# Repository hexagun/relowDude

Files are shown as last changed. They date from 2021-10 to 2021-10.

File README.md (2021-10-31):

# relowDude
Controller for reflow oven
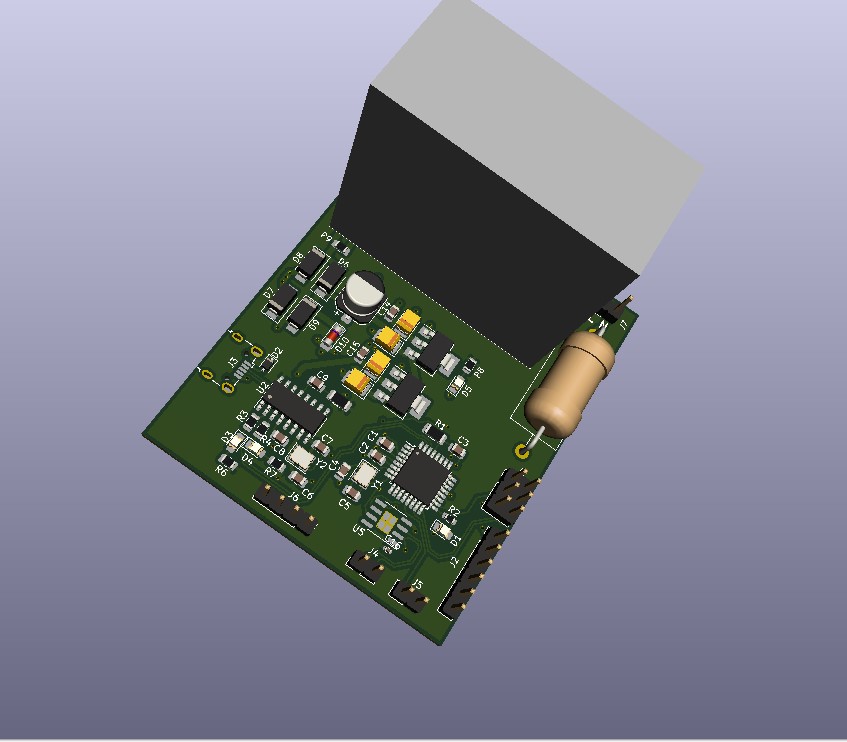
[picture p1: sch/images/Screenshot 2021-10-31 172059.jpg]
top1

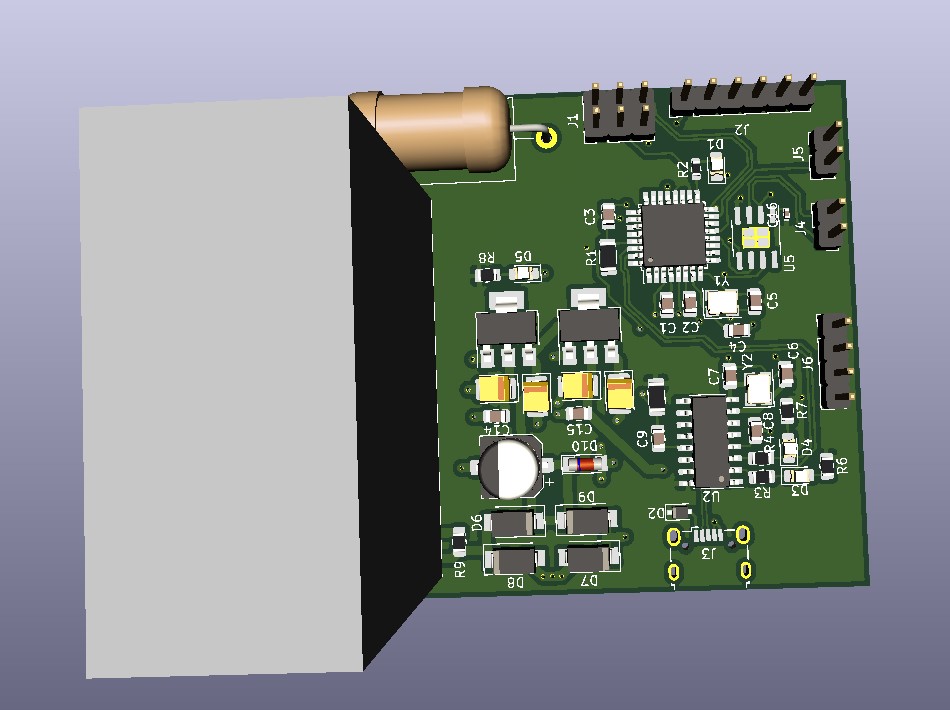
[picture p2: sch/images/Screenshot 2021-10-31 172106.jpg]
top2

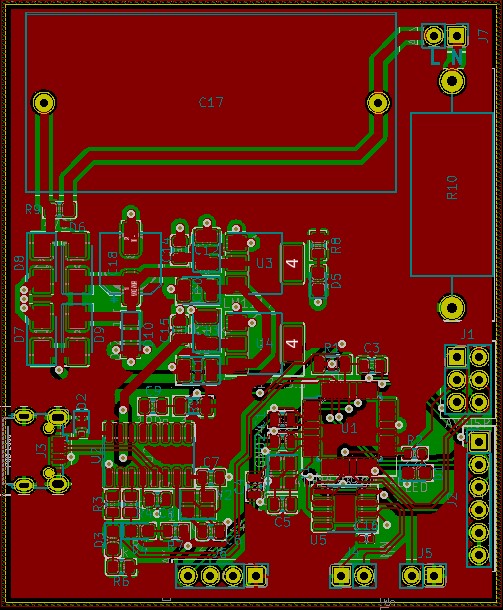
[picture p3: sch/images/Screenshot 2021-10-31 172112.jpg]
top3


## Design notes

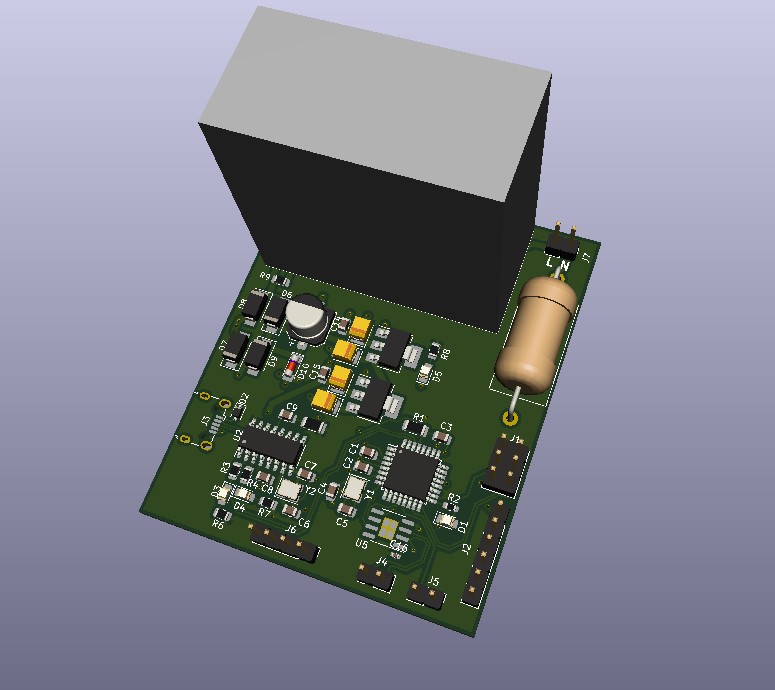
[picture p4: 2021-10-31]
sch/layoutFront.jpg

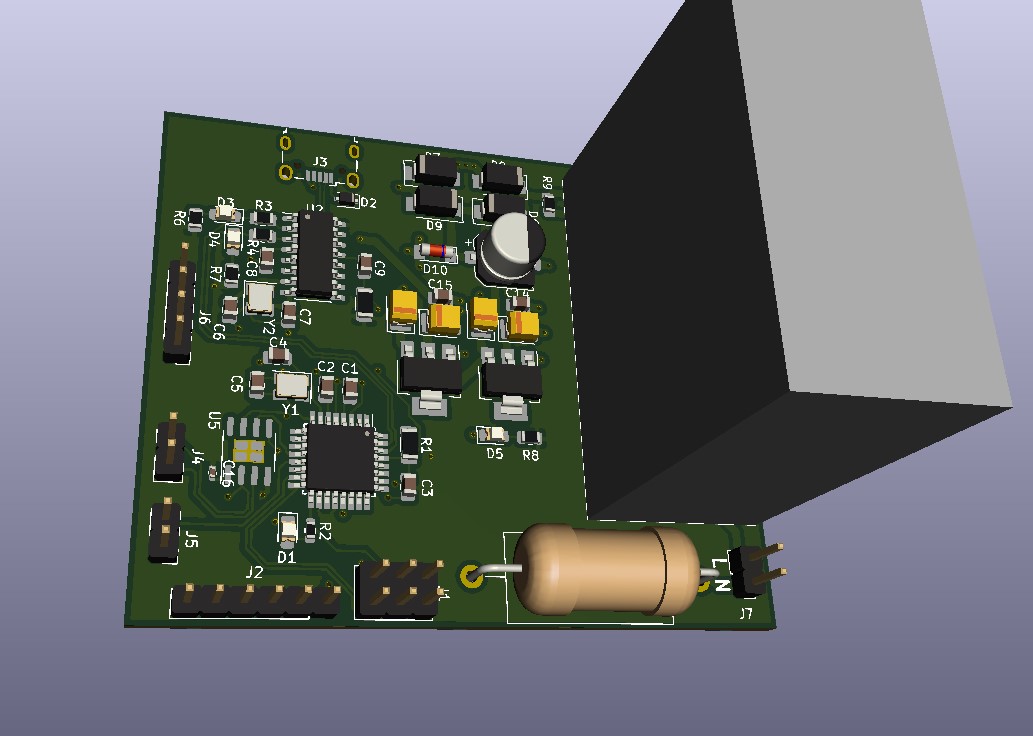
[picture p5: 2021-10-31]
sch/layoutFront1.jpg

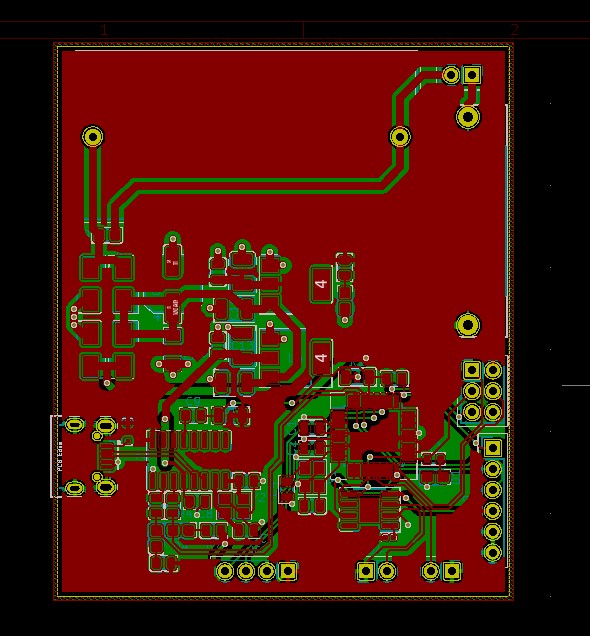
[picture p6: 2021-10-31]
sch/layout.jpg

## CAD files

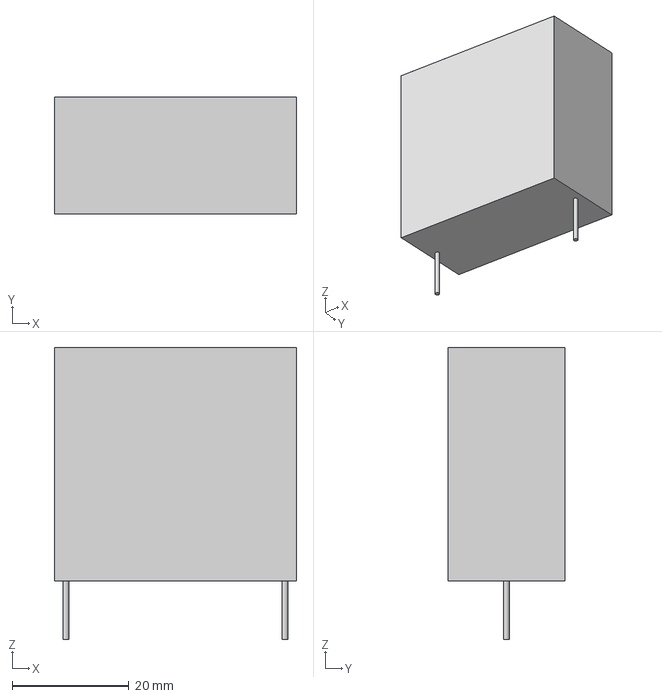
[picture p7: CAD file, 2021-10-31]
sch/R475W42205001K v1.step
41.5 x 20.0 x 50.0 mm

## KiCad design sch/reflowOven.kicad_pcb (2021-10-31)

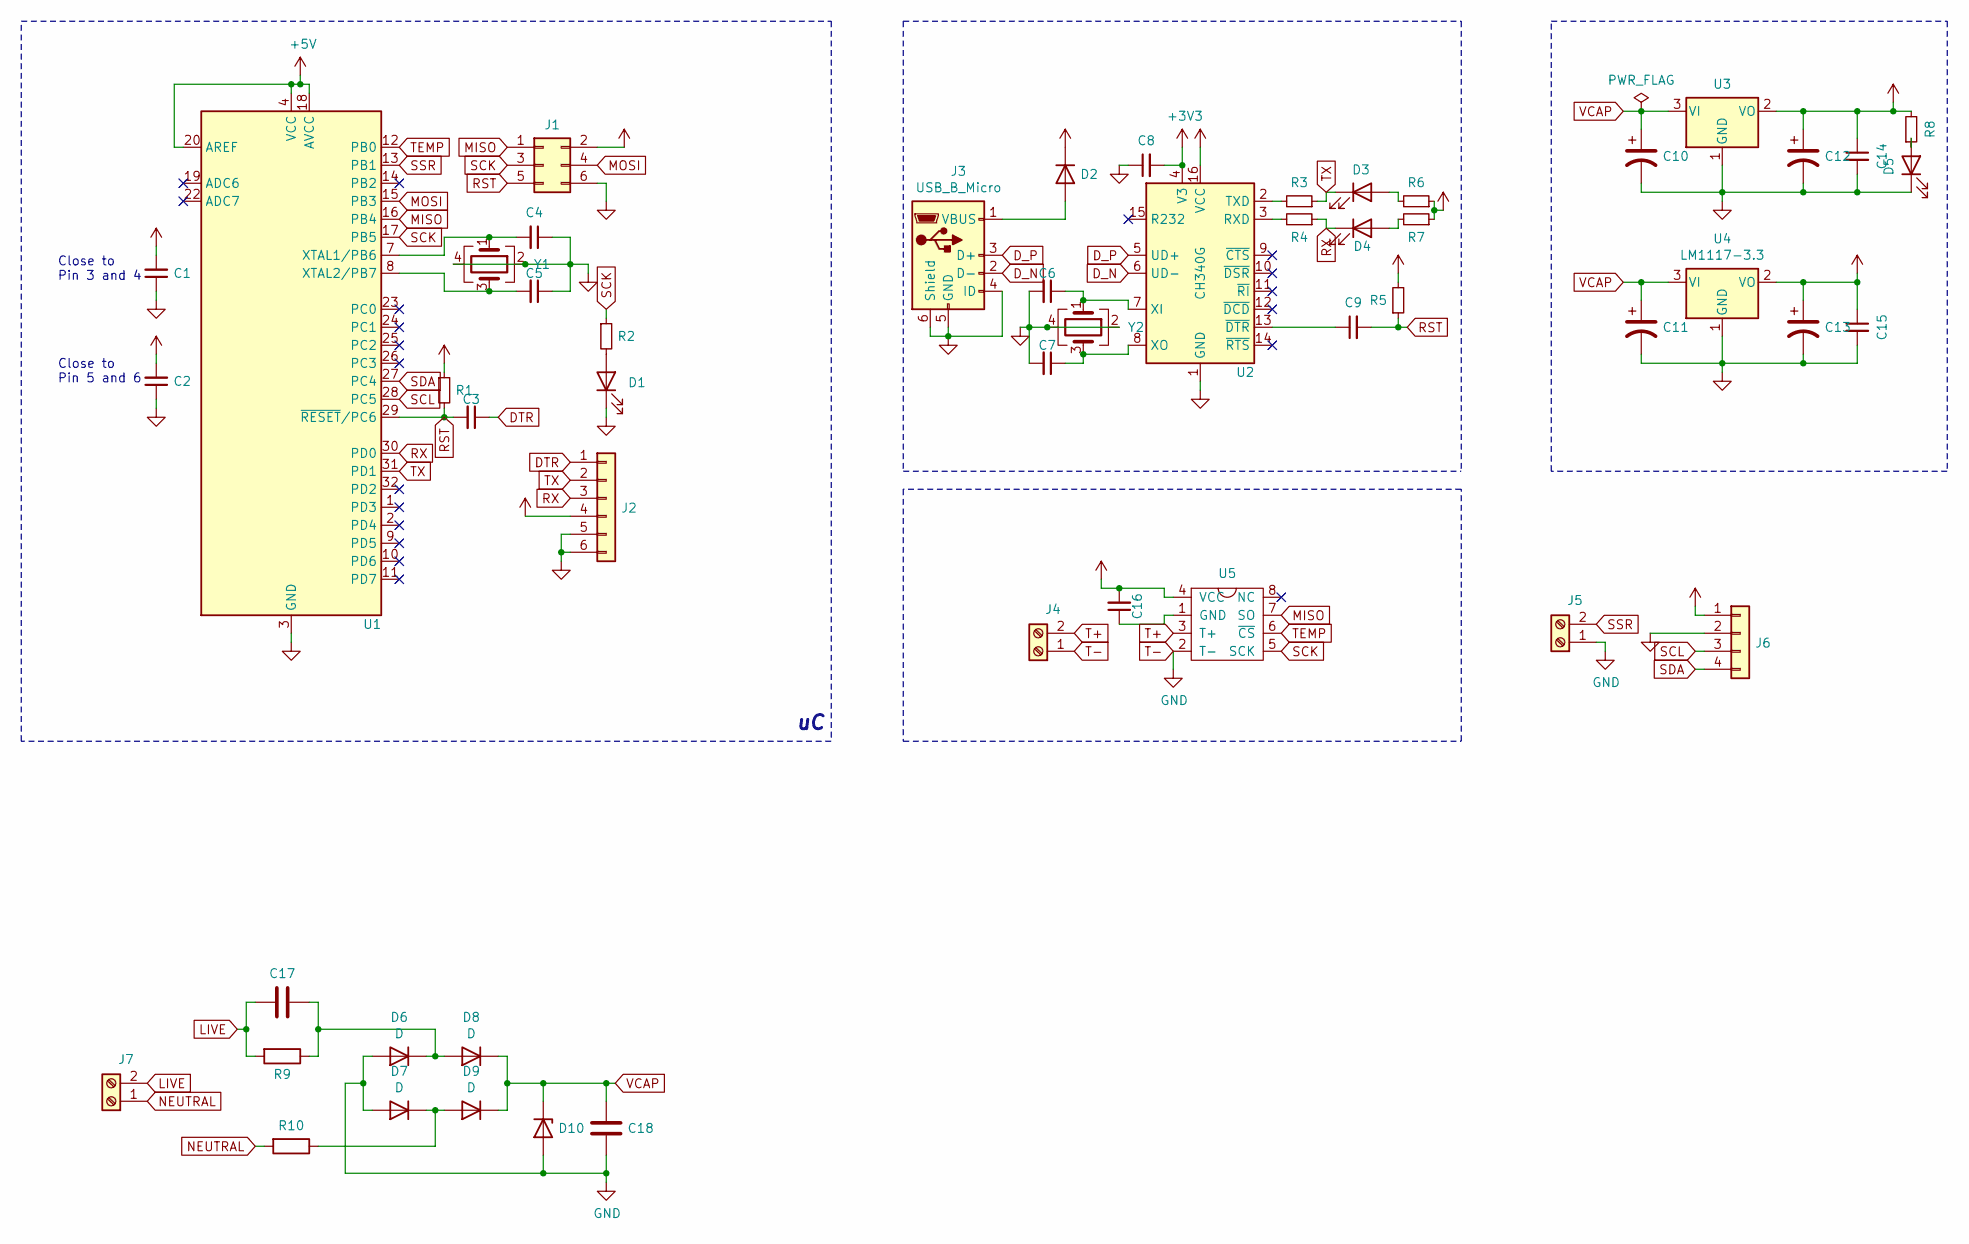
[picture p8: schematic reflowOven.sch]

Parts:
C1, C2, C3, C8, C9, C14, C15: 100n; C_0805_2012Metric; JLCPCB C49678
C4, C5, C6, C7: 22p; C_0805_2012Metric; JLCPCB C1804
C10, C11, C12, C13: 10u; CP_EIA-3528-21_Kemet-B; JLCPCB C119050
C16: 0.1u; C_0402_1005Metric; JLCPCB C361198
C17: 2.2u; R475W42205001K; Mouser R475W42205001K
C18: 47u; CP_Elec_6.3x5.9; JLCPCB C311666
D1: LED; LED_0805_2012Metric_Castellated; JLCPCB C84256
D2: 1N4007; D_SOD-323F; JLCPCB C193404
D3: TX; LED_0805_2012Metric_Castellated; JLCPCB C84256
D4: RX; LED_0805_2012Metric_Castellated; JLCPCB C84256
D5: ON; LED_0805_2012Metric_Castellated; JLCPCB C84256
D6, D7, D8, D9: D; D_SMA; JLCPCB C727081
D10: D_Zener; D_MiniMELF; JLCPCB C8061
J1: AVRISP; PinHeader_2x03_P2.54mm_Vertical
J2: UART; PinHeader_1x06_P2.54mm_Vertical
J3: USB_B_Micro; USB_Micro-B_Wuerth_629105150521; JLCPCB C879723
J4: TEMPCONN; PinHeader_1x02_P2.54mm_Vertical
J5: SSRCONN; PinHeader_1x02_P2.54mm_Vertical
J6: DISPLAY; PinHeader_1x04_P2.54mm_Vertical
J7: MAINS; PinHeader_1x02_P2.54mm_Vertical
R1, R5: 10k; R_1206_3216Metric; JLCPCB C17902
R2: 330; R_0603_1608Metric; JLCPCB C23140
R3, R4, R6, R7, R8: 1k; R_0805_2012Metric; JLCPCB C17513
R9: 470k; R_0805_2012Metric_Pad1.20x1.40mm_HandSolder; JLCPCB C17675
R10: 100; R_Axial_DIN0918_L18.0mm_D9.0mm_P25.40mm_Horizontal; Mouser 594-AC05W100R0J
U1: ATmega328P-AU; TQFP-32_7x7mm_P0.8mm; JLCPCB C14877
U2: CH340G; SOIC-16_3.9x9.9mm_P1.27mm; JLCPCB C14267
U3: LM1117-5.0; SOT-223; JLCPCB C131933
U4: LM1117-3.3; SOT-223; JLCPCB C23984
U5: MAX6675; SOIC-8-1EP_3.9x4.9mm_P1.27mm_EP2.29x3mm; JLCPCB C16030
Y1: Crystal_GND24; Crystal_SMD_3225-4Pin_3.2x2.5mm; JLCPCB C13738
Y2: Crystal_GND24; Crystal_SMD_3225-4Pin_3.2x2.5mm; JLCPCB C9002

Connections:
+3V3: C8.2, C13.1, C15.1, U2.4 (V3), U4.2 (VO)
+5V: C1.2, C2.2, C12.1, C14.1, C16.2, D2.1 (K), J1.2, J2.4, J6.1, R1.1, R5.2, R6.1, R7.1, R8.2, U1.4 (VCC), U1.6 (VCC), U1.18 (AVCC), U1.20 (AREF), U2.16 (VCC), U3.2 (VO), U5.4 (VCC)
DTR: C3.1, J2.1
D_N: J3.2 (D-), U2.6 (UD-)
D_P: J3.3 (D+), U2.5 (UD+)
LIVE: C17.2, J7.2, R9.2
MISO: J1.1, U1.16 (PB4), U5.7 (SO)
MOSI: J1.4, U1.15 (PB3)
NEUTRAL: J7.1, R10.2
unnamed: C4.2, U1.7 (XTAL1/PB6), Y1.1
unnamed: C5.2, U1.8 (XTAL2/PB7), Y1.3
unnamed: C6.1, U2.7 (XI), Y2.1
unnamed: C7.1, U2.8 (XO), Y2.3
unnamed: C9.1, U2.13 (~DTR)
unnamed: C16.1, U5.1 (GND)
unnamed: C17.1, D6.1 (K), D8.2 (A), R9.1
unnamed: D1.2 (A), R2.2
unnamed: D2.2 (A), J3.1 (VBUS)
unnamed: D3.2 (A), R6.2
unnamed: D4.2 (A), R7.2
unnamed: D5.2 (A), R8.1
unnamed: D7.1 (K), D9.2 (A), R10.1
unnamed: R3.2, U2.2 (TXD)
unnamed: R4.2, U2.3 (RXD)
RST: C3.2, C9.2, J1.5, R1.2, R5.1, U1.29 (~RESET~/PC6)
RX: D4.1 (K), J2.3, R4.1, U1.30 (PD0)
SCK: J1.3, R2.1, U1.17 (PB5), U5.5 (SCK)
SCL: J6.3, U1.28 (PC5)
SDA: J6.4, U1.27 (PC4)
SSR: J5.2, U1.13 (PB1)
T+: J4.2, U5.3 (T+)
T-: C1.1, C2.1, C4.1, C5.1, C6.2, C7.2, C8.1, C10.2, C11.2, C12.2, C13.2, C14.2, C15.2, C18.2, D1.1 (K), D5.1 (K), D6.2 (A), D7.2 (A), D10.2 (A), J1.6, J2.5, J2.6, J3.4 (ID), J3.5 (GND), J3.6 (Shield), J4.1, J5.1, J6.2, U1.3 (GND), U1.5 (GND), U1.21 (GND), U2.1 (GND), U3.1 (GND), U4.1 (GND), U5.2 (T-), Y1.2, Y1.4, Y2.2, Y2.4
TEMP: U1.12 (PB0), U5.6 (~CS)
TX: D3.1 (K), J2.2, R3.1, U1.31 (PD1)
VCAP: C10.1, C11.1, C18.1, D8.1 (K), D9.1 (K), D10.1 (K), U3.3 (VI), U4.3 (VI)

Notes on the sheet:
Close to Pin 3 and 4
Close to Pin 5 and 6

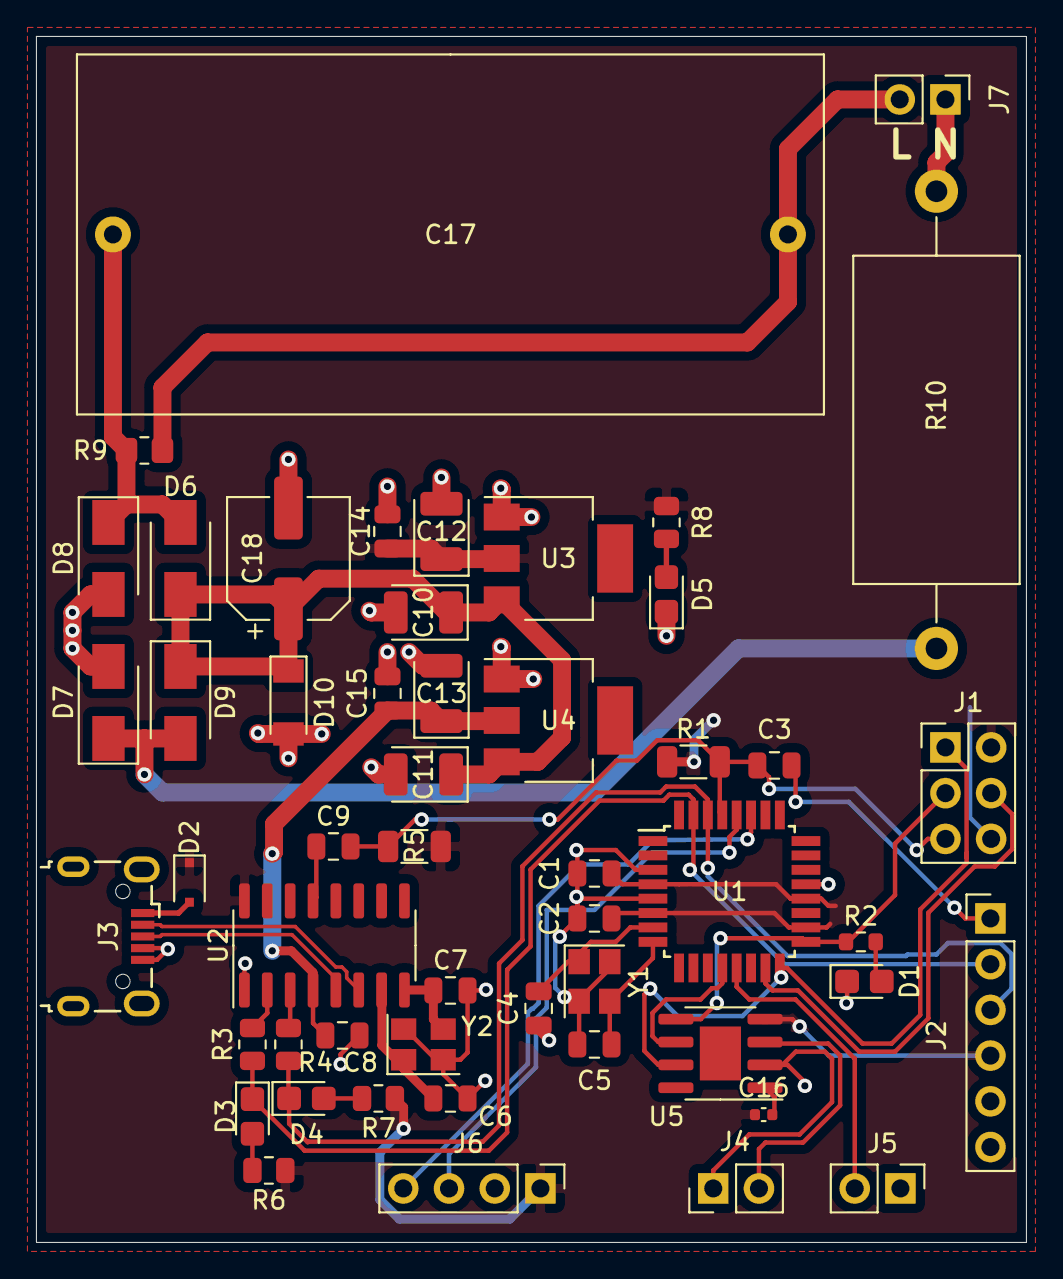
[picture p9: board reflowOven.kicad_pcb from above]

Board: 2 copper layers, 55.0 x 67.0 mm, 52 parts (0 on the bottom side), 35 nets.
